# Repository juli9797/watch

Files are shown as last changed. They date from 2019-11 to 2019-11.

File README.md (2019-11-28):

# WATCH   
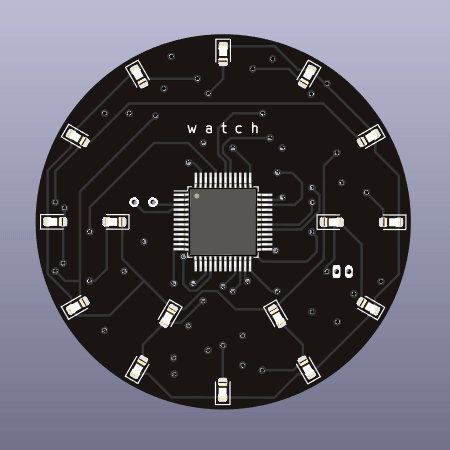
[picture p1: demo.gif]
watch gif


This is a simple LED-wristwatch with 16 LEDs and one push button.
Everything is controlled by a STM32F103 and its realtime clock.
Time is visualized using 12 LEDs for the hours and 5 minute steps and 4 additional LEDs to indicate minute%5 .
The current hour LED will light up steady while the minute LEDs flash slowly.

## Specs:   
* handles 1S LIPO
* 38mm diameter
* 4 Layer PCB
* exposed I2C and UART interface for future extensions

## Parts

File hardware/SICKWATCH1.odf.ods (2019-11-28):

Ref | Qnty | Value | Cmp name | Footprint | Description | Vendor
C1, C2, | 2 | 33p | C | Capacitor_SMD:C_0603_1608Metric | Unpolarized capacitor
C6, | 1 | 1u | C | Capacitor_SMD:C_0603_1608Metric | Unpolarized capacitor
C10, C12, C11, C14, C4, C5, C7, C8, C9, C15, | 10 | 100n | C | Capacitor_SMD:C_0603_1608Metric | Unpolarized capacitor
C13, C3, | 2 | 4u7 | C | Capacitor_SMD:C_0603_1608Metric | Unpolarized capacitor
D16, D14, D13, D12, D10, D9, D8, D6, D5, D4, D2, D1, D15, D11, D7, D3, | 16 | LED | LED | LED_SMD:LED_0603_1608Metric | Light emitting diode
J1, | 1 | Conn_01x02_Female | Conn_01x02_Female | Connector_Molex:Molex_PicoBlade_53048-0210_1x02_P1.25mm_Horizontal | Generic connector, single row, 01x02, script generated (kicad-library-utils/schlib/autogen/connector/)
J2, | 1 | Conn_01x02_Female | Conn_01x02_Female | Resistor_SMD:R_1206_3216Metric | Generic connector, single row, 01x02, script generated (kicad-library-utils/schlib/autogen/connector/)
MUX_H1, | 1 | SN74LV4051A | SN74LV4051A-TI | Package_SO:TSSOP-16_4.4x5mm_P0.65mm
Q2, Q3, | 2 | BSS138 | BSS138 | Package_TO_SOT_SMD:SOT-23 | 50V Vds, 0.22A Id, N-Channel MOSFET, SOT-23
R3, R5, R2, R4, | 4 | 0 | R | Resistor_SMD:R_0603_1608Metric | Resistor
R6, R1, | 2 | 100k | R | Resistor_SMD:R_0603_1608Metric | Resistor
R11, R13, R15, R7, | 4 | R | R | Resistor_SMD:R_0603_1608Metric | Resistor
R12, R14, R8, | 3 | 10k | R | Resistor_SMD:R_0603_1608Metric | Resistor
R17, R16, R9, | 3 | 1k | R | Resistor_SMD:R_0603_1608Metric | Resistor
SW1, | 1 | SW_Push | SW_Push | Button_Switch_SMD:Panasonic_EVQPUK_EVQPUB | Push button switch, generic, two pins
U1, | 1 | STM32F103C8Tx | STM32F103C8Tx | Package_QFP:LQFP-48_7x7mm_P0.5mm | ARM Cortex-M3 MCU, 64KB flash, 20KB RAM, 72MHz, 2-3.6V, 37 GPIO, LQFP-48
U2, | 1 | TLV71333PDBV | TLV71333PDBV | Package_TO_SOT_SMD:SOT-23-5 | 150mA Low Dropout Voltage Regulator, Fixed Output 3.3V, SOT-23-5
U3, | 1 | MCP73831-2-OT | MCP73831-2-OT | Package_TO_SOT_SMD:SOT-23-5 | Single cell, Li-Ion/Li-Po charge management controller, 4.20V, Tri-State Status Output, in SOT23-5 package
U4, | 1 | 74LVC1G17 | 74LVC1G17 | Package_TO_SOT_SMD:SOT-23-5 | Single Schmitt Buffer Gate, Low-Voltage CMOS
Y1, | 1 | Crystal | Crystal | Crystal:Crystal_C26-LF_D2.1mm_L6.5mm_Horizontal | Two pin crystal

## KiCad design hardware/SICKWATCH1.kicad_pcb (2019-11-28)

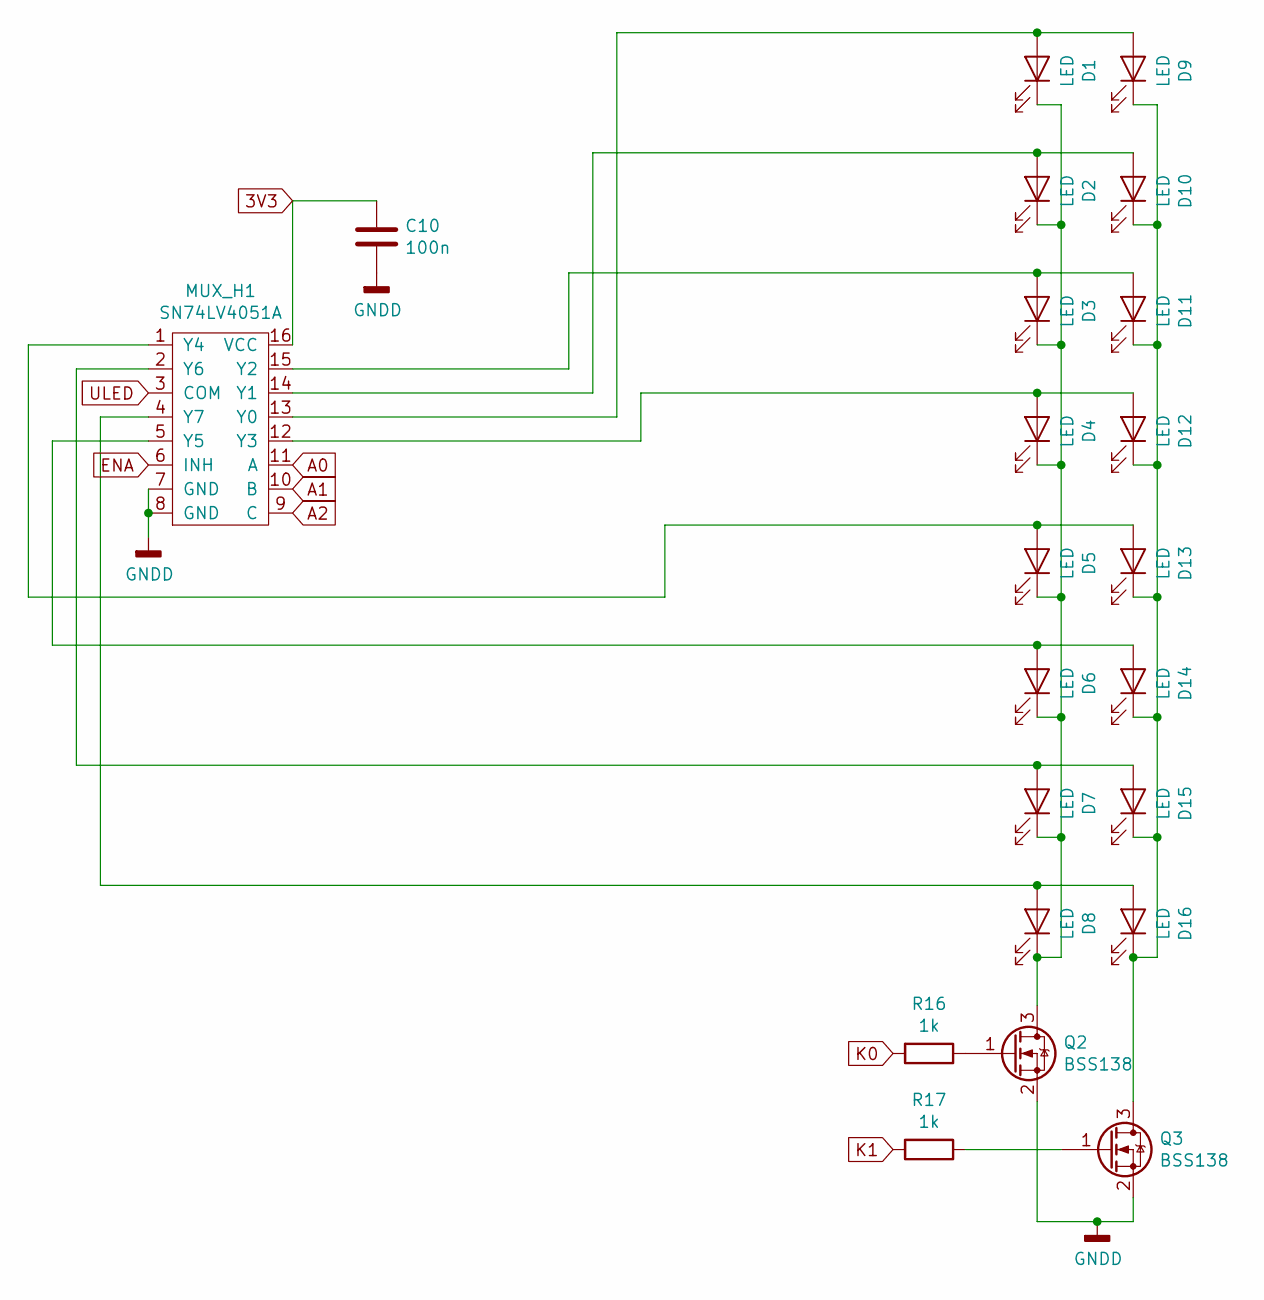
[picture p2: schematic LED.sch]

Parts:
C10: 100n; C_0603_1608Metric
D1, D2, D3, D4, D5, D6, D7, D8, D9, D10, D11, D12, D13, D14, D15, D16: LED; LED_0603_1608Metric
MUX?1: SN74LV4051A; TSSOP-16_4.4x5mm_P0.65mm
Q2, Q3: BSS138; SOT-23
R16, R17: 1k; R_0603_1608Metric

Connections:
3V3: C10.1; also elsewhere on the board
GND: C10.2, Q2.2 (S), Q3.2 (S); also elsewhere on the board
K0: R16.2; also elsewhere on the board
K1: R17.2; also elsewhere on the board
unnamed: D1.1 (K), D2.1 (K), D3.1 (K), D4.1 (K), D5.1 (K), D6.1 (K), D7.1 (K), D8.1 (K), Q2.3 (D)
unnamed 16: D1.2 (A), D9.2 (A); also elsewhere on the board
unnamed: D9.1 (K), D10.1 (K), D11.1 (K), D12.1 (K), D13.1 (K), D14.1 (K), D15.1 (K), D16.1 (K), Q3.3 (D)
unnamed 18: D2.2 (A), D10.2 (A); also elsewhere on the board
unnamed 19: D3.2 (A), D11.2 (A); also elsewhere on the board
unnamed 20: D4.2 (A), D12.2 (A); also elsewhere on the board
unnamed 21: D5.2 (A), D13.2 (A); also elsewhere on the board
unnamed 22: D6.2 (A), D14.2 (A); also elsewhere on the board
unnamed 23: D7.2 (A), D15.2 (A); also elsewhere on the board
unnamed 24: D8.2 (A), D16.2 (A); also elsewhere on the board
unnamed: Q2.1 (G), R16.1
unnamed: Q3.1 (G), R17.1

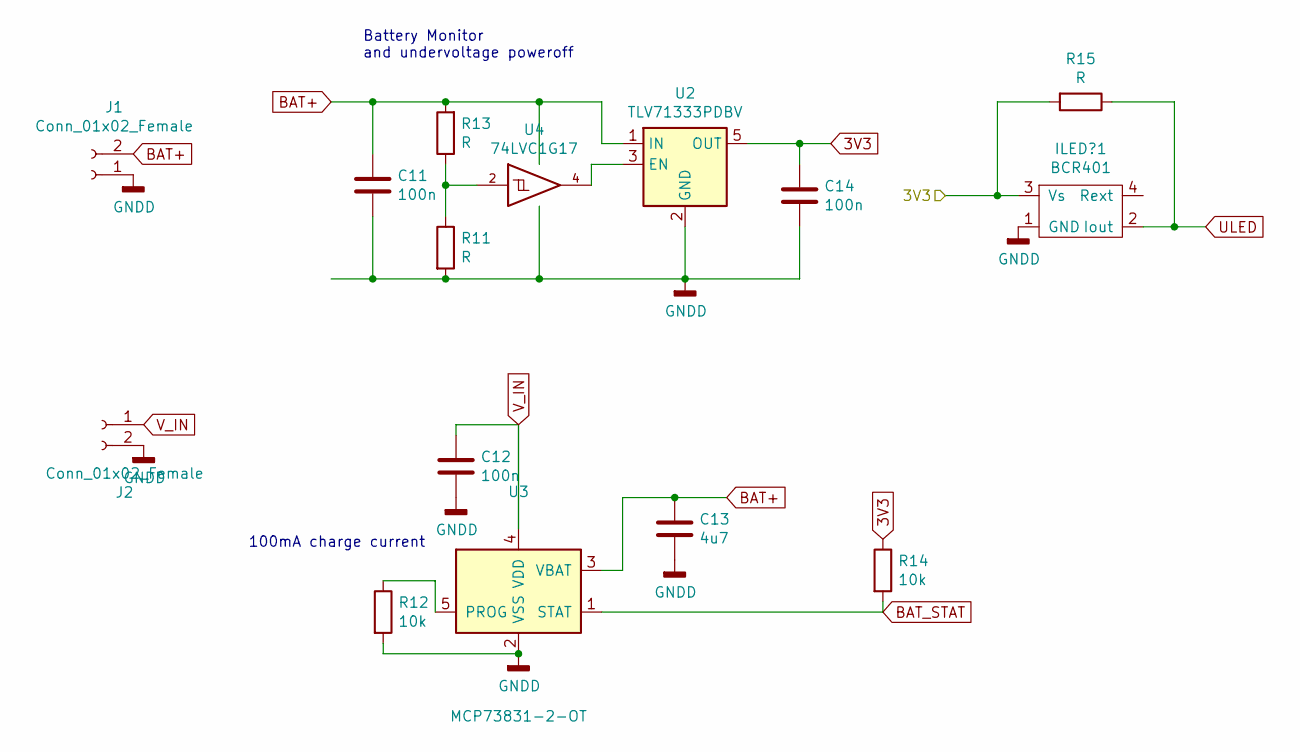
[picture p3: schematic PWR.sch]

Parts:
C11, C12, C14: 100n; C_0603_1608Metric
C13: 4u7; C_0603_1608Metric
ILED?1: BCR401; SOT-143R_Reverse
J1: Conn_01x02_Female; Molex_PicoBlade_53048-0210_1x02_P1.25mm_Horizontal
J2: Conn_01x02_Female; R_1206_3216Metric
R11, R13, R15: R; R_0603_1608Metric
R12, R14: 10k; R_0603_1608Metric
U2: TLV71333PDBV; SOT-23-5
U3: MCP73831-2-OT; SOT-23-5
U4: 74LVC1G17; SOT-23-5

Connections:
3V3: C14.1, ILED?1.3 (Vs), R14.1, R15.2, U2.5 (OUT); also elsewhere on the board
BAT+: C11.1, C13.1, J1.2, R13.2, U2.1 (IN), U3.3 (VBAT), U4.5 (VCC)
BAT_STAT: R14.2, U3.1 (STAT); also elsewhere on the board
GND: C11.2, C12.2, C13.2, C14.2, ILED?1.1 (GND), J1.1, J2.2, R11.2, R12.2, U2.2 (GND), U3.2 (VSS), U4.3 (GND); also elsewhere on the board
unnamed: R11.1, R13.1, U4.2
unnamed: R12.1, U3.5 (PROG)
unnamed: U2.3 (EN), U4.4
ULED: ILED?1.2 (Iout), R15.1; also elsewhere on the board
V_IN: C12.1, J2.1, U3.4 (VDD)

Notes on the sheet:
Battery Monitor and undervoltage poweroff
100mA charge current

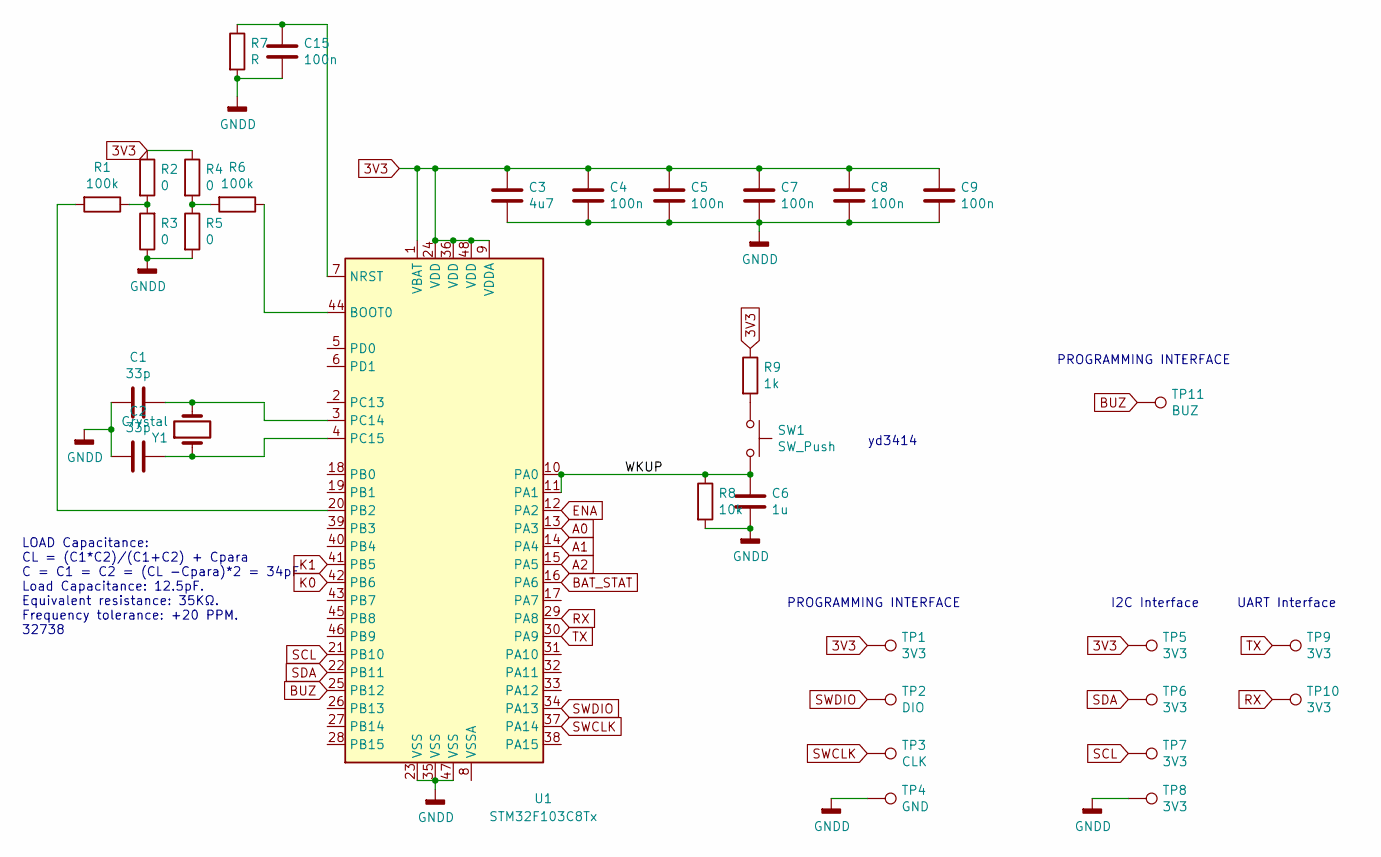
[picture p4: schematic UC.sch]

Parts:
C1, C2: 33p; C_0603_1608Metric
C3: 4u7; C_0603_1608Metric
C4, C5, C7, C8, C9, C15: 100n; C_0603_1608Metric
C6: 1u; C_0603_1608Metric
R1, R6: 100k; R_0603_1608Metric
R2, R3, R4, R5: 0; R_0603_1608Metric
R7: R; R_0603_1608Metric
R8: 10k; R_0603_1608Metric
R9: 1k; R_0603_1608Metric
SW1: SW_Push; Panasonic_EVQPUK_EVQPUB
TP1, TP5, TP6, TP7, TP8, TP9, TP10: 3V3; TestPoint_Pad_D1.0mm
TP2: DIO; TestPoint_Pad_D1.0mm
TP3: CLK; TestPoint_Pad_D1.0mm
TP4: GND; TestPoint_Pad_D1.0mm
TP11: BUZ; TestPoint_Pad_D1.0mm
U1: STM32F103C8Tx; LQFP-48_7x7mm_P0.5mm
Y1: Crystal; Crystal_C26-LF_D2.1mm_L6.5mm_Horizontal

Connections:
3V3: C3.1, C4.1, C5.1, C7.1, C8.1, C9.1, R2.1, R4.1, R9.1, TP1.1, TP5.1, U1.1 (VBAT), U1.9 (VDDA), U1.24 (VDD), U1.36 (VDD), U1.48 (VDD); also elsewhere on the board
/Sheet5CD3F32F/WKUP: C6.1, R8.1, SW1.2, U1.10 (PA0), U1.11 (PA1)
A0: U1.13 (PA3); also elsewhere on the board
A1: U1.14 (PA4); also elsewhere on the board
A2: U1.15 (PA5); also elsewhere on the board
BAT_STAT: U1.16 (PA6); also elsewhere on the board
BUZ: TP11.1, U1.25 (PB12)
ENA: U1.12 (PA2); also elsewhere on the board
GND: C1.2, C2.2, C3.2, C4.2, C5.2, C6.2, C7.2, C8.2, C9.2, C15.2, R3.1, R5.2, R7.2, R8.2, TP4.1, TP8.1, U1.23 (VSS), U1.35 (VSS), U1.47 (VSS); also elsewhere on the board
K0: U1.42 (PB6); also elsewhere on the board
K1: U1.41 (PB5); also elsewhere on the board
unnamed: C1.1, U1.3 (PC14), Y1.2
unnamed: C2.1, U1.4 (PC15), Y1.1
unnamed: C15.1, R7.1, U1.7 (NRST)
unnamed: R1.1, R2.2, R3.2
unnamed: R1.2, U1.20 (PB2)
unnamed: R4.2, R5.1, R6.2
unnamed: R6.1, U1.44 (BOOT0)
unnamed: R9.2, SW1.1
RX: TP10.1, U1.29 (PA8)
SCL: TP7.1, U1.21 (PB10)
SDA: TP6.1, U1.22 (PB11)
SWCLK: TP3.1, U1.37 (PA14)
SWDIO: TP2.1, U1.34 (PA13)
TX: TP9.1, U1.30 (PA9)

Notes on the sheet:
PROGRAMMING INTERFACE
LOAD Capacitance: CL = (C1*C2)/(C1+C2) + Cpara C = C1 = C2 = (CL -Cpara)*2 = 34pF Load Capacitance: 12.5pF. Equivalent resistance: 35KΩ. Frequency tolerance: +20 PPM. 32738
I2C Interface
UART Interface
yd3414

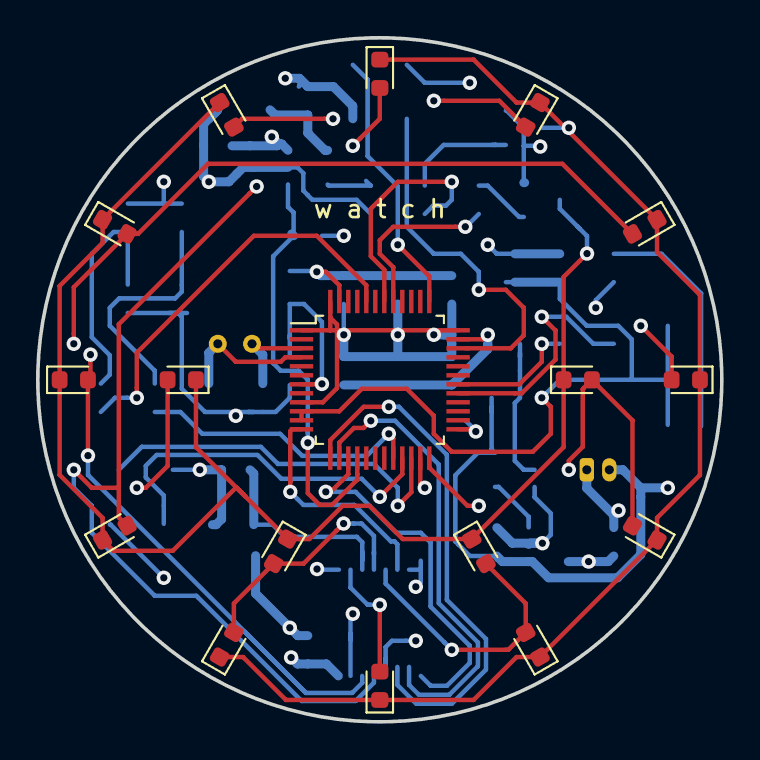
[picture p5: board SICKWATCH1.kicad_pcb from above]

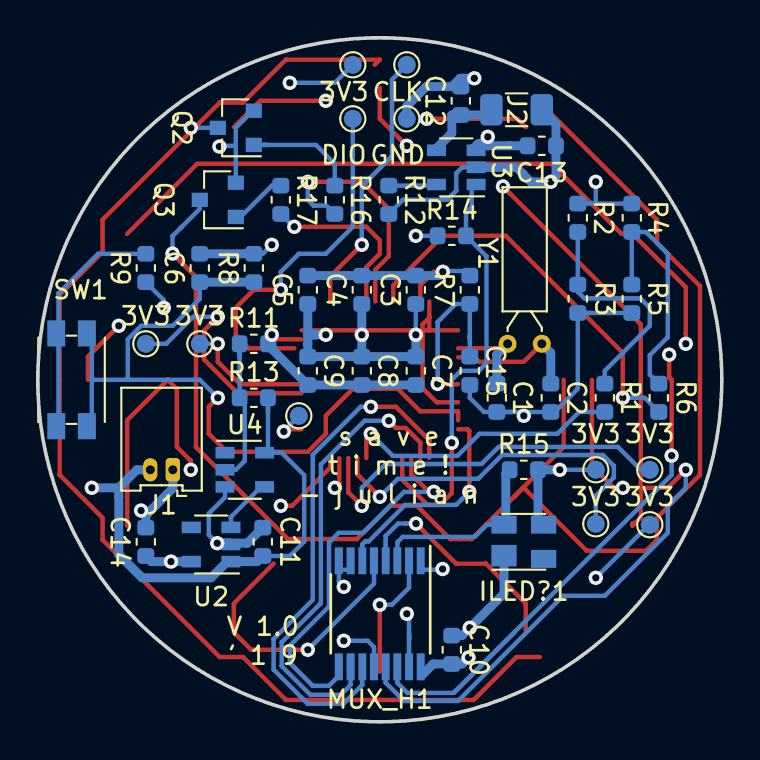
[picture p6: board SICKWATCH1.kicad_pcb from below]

Board: 4 copper layers, 38.0 x 38.0 mm, 70 parts (53 on the bottom side), 43 nets.

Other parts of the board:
MUX_H1: SN74LV4051A; TSSOP-16_4.4x5mm_P0.65mm

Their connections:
3V3: MUX_H1.16; also elsewhere on the board
A0: MUX_H1.11; also elsewhere on the board
A1: MUX_H1.10; also elsewhere on the board
A2: MUX_H1.9; also elsewhere on the board
ENA: MUX_H1.6; also elsewhere on the board
GND: MUX_H1.7, MUX_H1.8; also elsewhere on the board
unnamed 16: MUX_H1.13; also elsewhere on the board
unnamed 18: MUX_H1.14; also elsewhere on the board
unnamed 19: MUX_H1.15; also elsewhere on the board
unnamed 20: MUX_H1.12; also elsewhere on the board
unnamed 21: MUX_H1.1; also elsewhere on the board
unnamed 22: MUX_H1.5; also elsewhere on the board
unnamed 23: MUX_H1.2; also elsewhere on the board
unnamed 24: MUX_H1.4; also elsewhere on the board
ULED: MUX_H1.3; also elsewhere on the board

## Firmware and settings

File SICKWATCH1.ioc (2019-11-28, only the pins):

Mcu.UserName=STM32F103C8Tx
PA0-WKUP.Signal=SYS_WKUP
PA1.GPIO_Label=SWITCH
PA1.Signal=GPIO_Input
PA10.Signal=USART1_RX
PA13.Signal=SYS_JTMS-SWDIO
PA14.Signal=SYS_JTCK-SWCLK
PA2.GPIO_Label=EN_A
PA2.Signal=GPIO_Output
PA3.GPIO_Label=A1
PA3.Signal=GPIO_Output
PA4.GPIO_Label=A2
PA4.Signal=GPIO_Output
PA5.GPIO_Label=A3
PA5.Signal=GPIO_Output
PA6.GPIO_Label=BAT_STAT
PA6.Signal=GPIO_Input
PA9.Signal=USART1_TX
PB10.Signal=I2C2_SCL
PB11.Signal=I2C2_SDA
PB12.GPIO_Label=BUZ
PB12.Signal=GPIO_Output
PB5.GPIO_Label=K1
PB5.Signal=GPIO_Output
PB6.GPIO_Label=K0
PB6.Signal=GPIO_Output
PC14-OSC32_IN.Signal=RCC_OSC32_IN
PC15-OSC32_OUT.Signal=RCC_OSC32_OUT

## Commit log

2019-11-22 finished layout
    [SICKWATCH1.kicad_pcb]
2019-11-22 fixed screenprints
    [LED.sch, SICKWATCH1.kicad_pcb, UC.sch]
2019-11-27 Layout done (I GUESS)
    [PWR.sch, SICKWATCH1.kicad_pcb]
2019-11-28 finished V1.0 and ordered pcbs
    [LED.sch, PWR.sch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]
2019-11-28 more cleanup
    [LED.sch, PWR.sch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]
